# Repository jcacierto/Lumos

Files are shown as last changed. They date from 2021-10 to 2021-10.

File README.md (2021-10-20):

# Lumos
Low-cost, modular luminometer 

**How it works** \
Lumos is a low cost, modular luminometer which can measure the light intensity of luminescent enzymes. The device works by 
measuring the light intensity of the analyte through a TSL237 Light-to-Frequency photodiode. The sensor then converts the
incident light into a 50% duty cycle square wave voltage, which is then picked up by the ESP32 microcontroller's interrupt pins. 
At every rising edge of the square wave input, the microcontroller will call the interrupt service routine (ISR), which increments
the counter variable by 1. The value held by the counter variable is then measured after one second in order to determine the 
frequency in Hz. The frequency detected is directly proportional to the light intensity received from the light source. The output
is then displayed through either the LCD screen built in with the sensor, or on a mobile phone application (currently only available
on Android). The mobile application was made on Thunkable to facilitate BLE connection between the client (phone) and the server (ESP32).

**Materials** 
* ESP32 microcontroller
* TSL237 light-to-frequency photodiode
* LCD1602 screen (with I2C module built-in)
* 0.1uF capacitor
* PLA (for 3D printing)
* Wires

**How to Build**
1. Follow the schematic diagram for the correct wiring on the ESP32 microcontroller. 
2. Upload the .ino sketch to the microcontroller. 
3. On the Thunkable app, search up 'Lumos' by *johncedricaciertot*.
4. Print the CAD models.

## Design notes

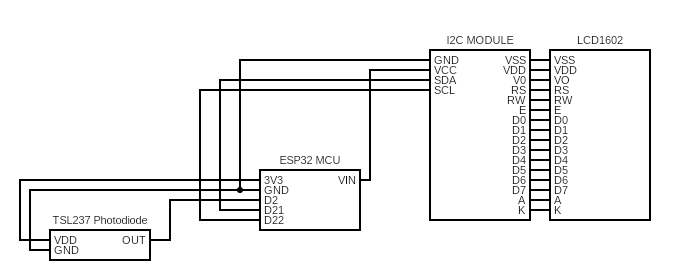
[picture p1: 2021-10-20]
Lumos-Schematic.png

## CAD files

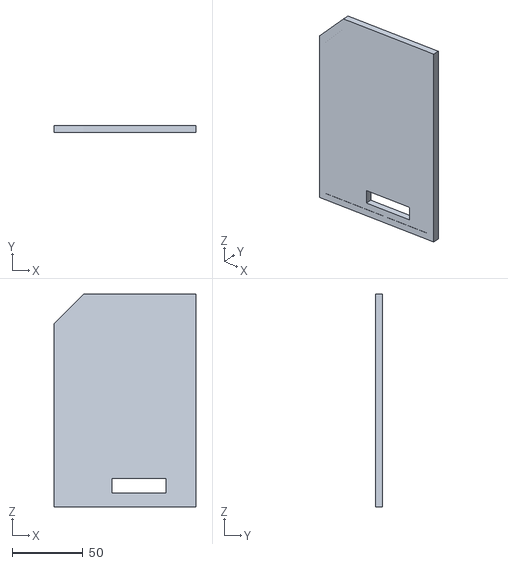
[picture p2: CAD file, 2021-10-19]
stl_files/Main Chassis /MainChassis_Left.stl
100.0 x 5.18 x 150.0

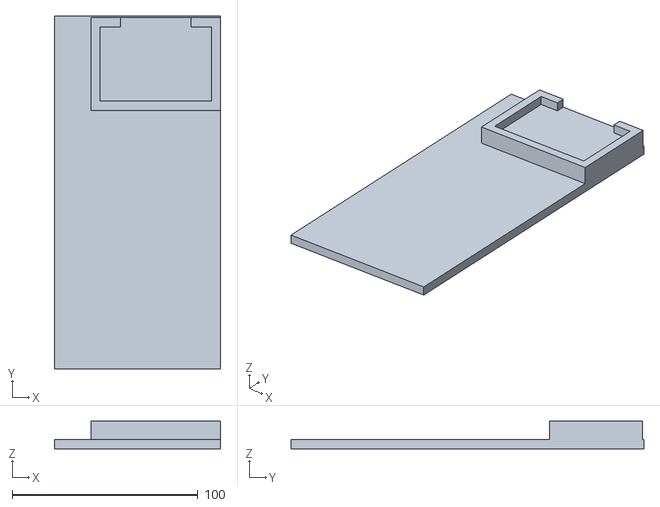
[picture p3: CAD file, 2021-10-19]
stl_files/Main Chassis /MainChassis_Bottom.stl
89.4 x 189.9 x 14.9

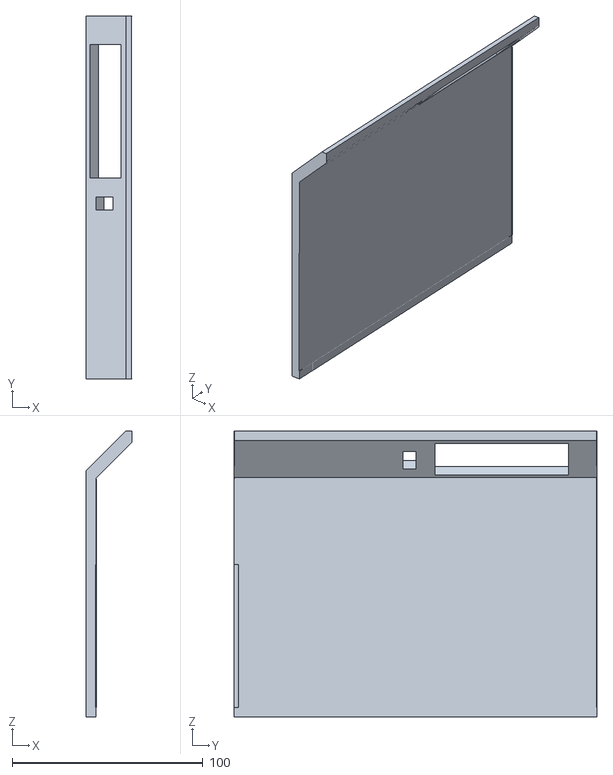
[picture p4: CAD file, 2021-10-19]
stl_files/Main Chassis /MainChassis_Front.stl
23.9 x 190.2 x 150.0

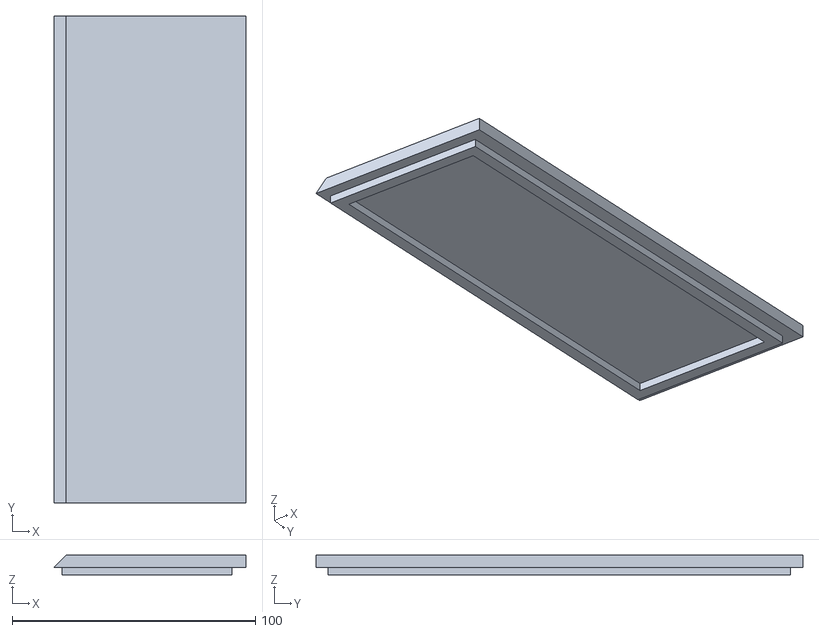
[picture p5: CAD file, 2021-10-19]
stl_files/Main Chassis /MainChassis_Cover.stl
78.9 x 200.1 x 8.10

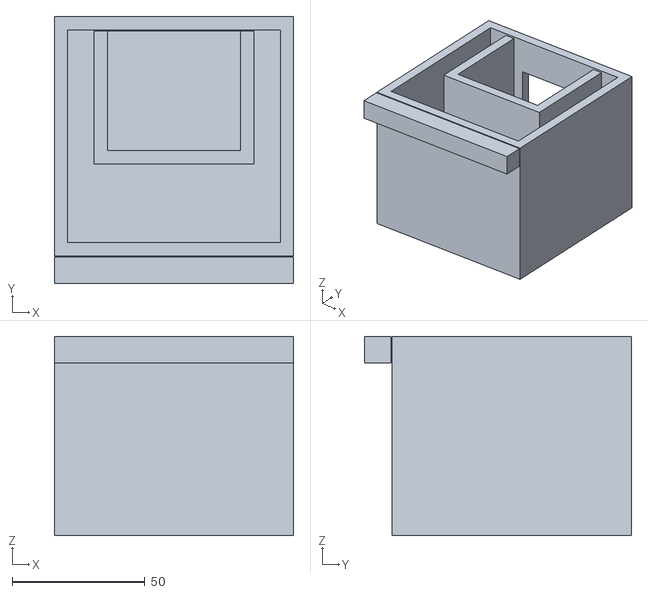
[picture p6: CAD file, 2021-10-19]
stl_files/Sample Chamber/SampleChamber_Main.stl
90.0 x 100.4 x 75.0

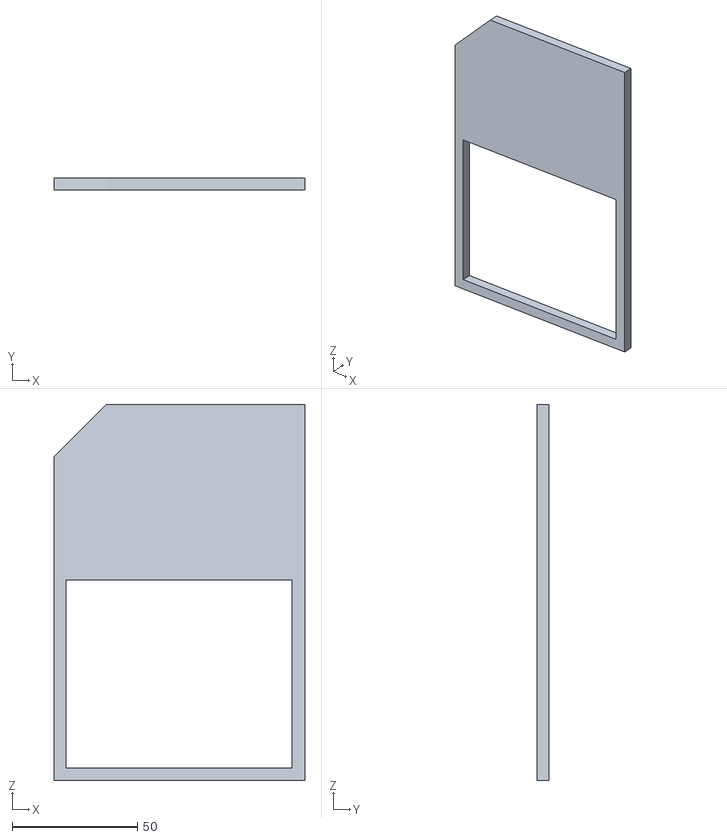
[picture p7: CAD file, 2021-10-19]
stl_files/Main Chassis /MainChassis_Right.stl
100.0 x 4.80 x 150.0

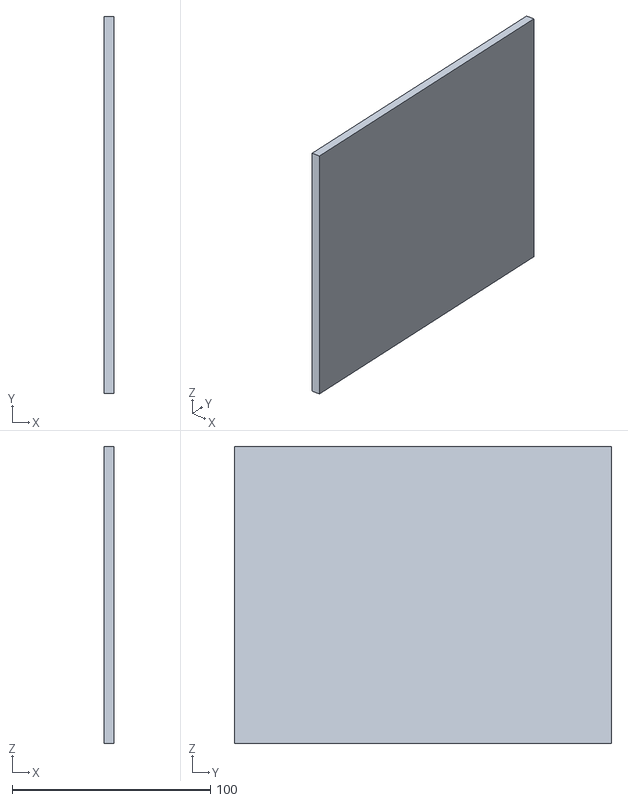
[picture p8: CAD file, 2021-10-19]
stl_files/Main Chassis /MainChassis_Back.stl
4.99 x 190.1 x 150.0

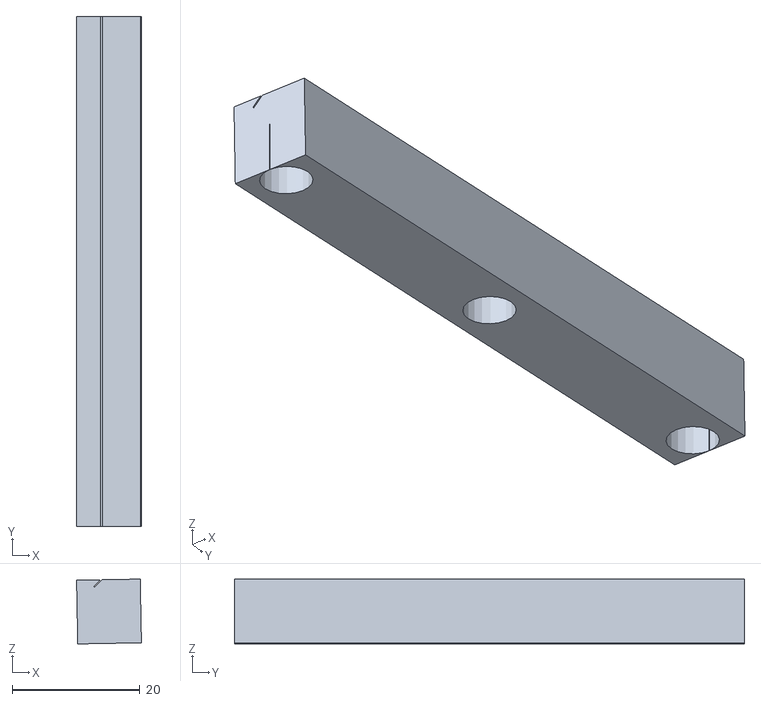
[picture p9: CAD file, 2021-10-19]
stl_files/LCD Holder/LCDHolder_Detachable.stl
10.2 x 80.0 x 10.2

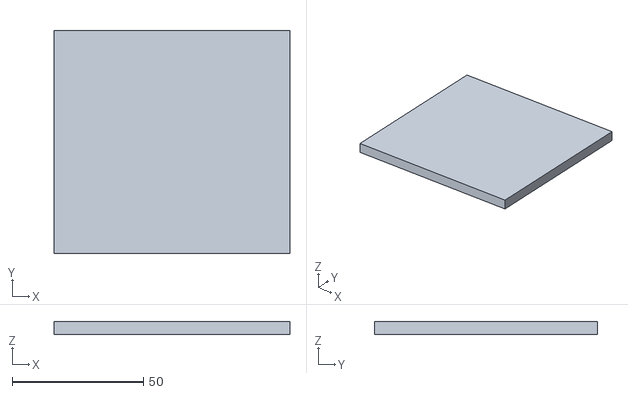
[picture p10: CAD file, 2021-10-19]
stl_files/Sample Chamber/SampleChamber_Top.stl
90.0 x 85.0 x 5.00

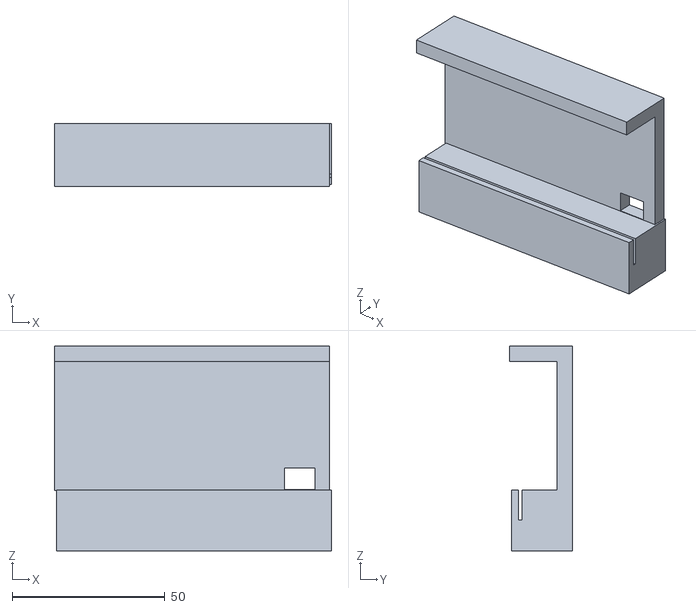
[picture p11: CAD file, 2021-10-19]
stl_files/Sensor Holder/SensorHolder.stl
90.6 x 20.6 x 67.0

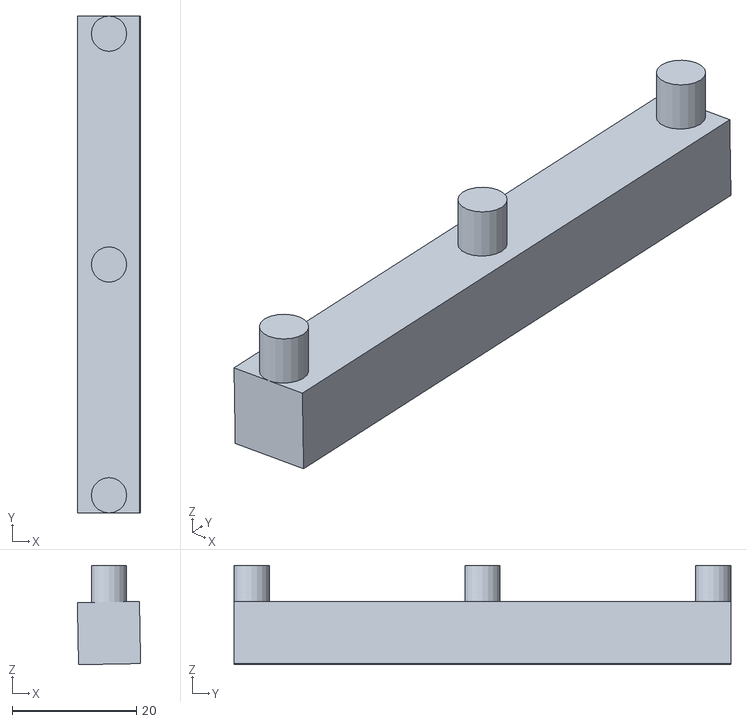
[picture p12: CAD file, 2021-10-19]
stl_files/LCD Holder/LCDHolder_Immobilized.stl
10.2 x 80.0 x 16.0

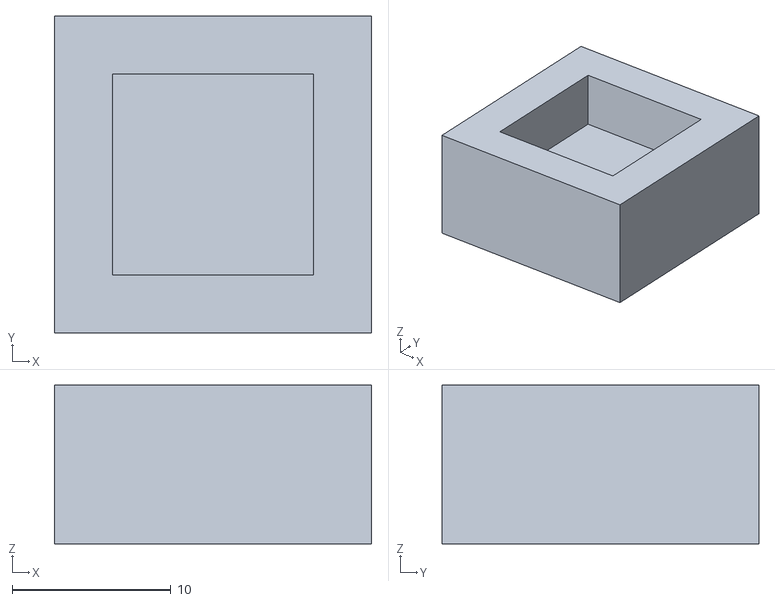
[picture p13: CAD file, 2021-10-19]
stl_files/Sample Chamber/SampleChamber_CuvetteHolder.stl
20.0 x 20.0 x 10.0

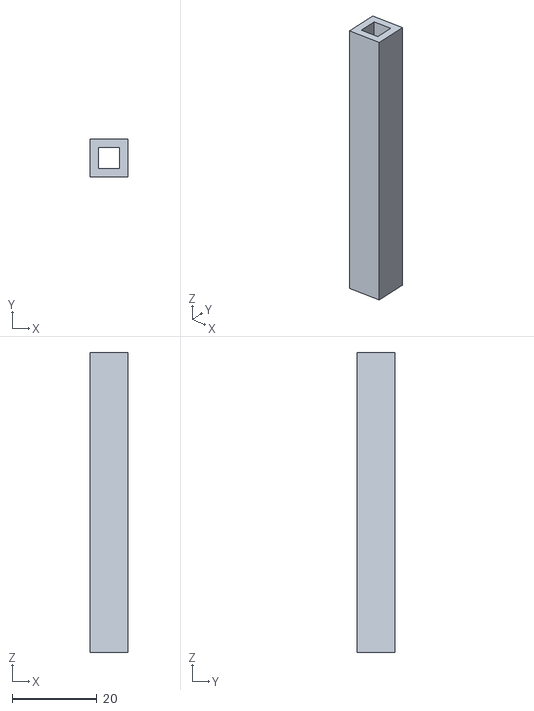
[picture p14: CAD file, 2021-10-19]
stl_files/Sample Chamber/SampleChamber_LDRHolder.stl
9.00 x 9.00 x 71.0

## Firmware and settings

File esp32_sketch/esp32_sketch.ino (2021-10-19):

/**
   Main code for frequency detection of TSL237 sensor
   was heavily based on a pre-written code made by Rob Tillaart
   Made: 2011 - 05 - 16
   Source: https://playground.arduino.cc/Main/TSL235R/

   BLE functionalities were based on code written by Neil Kolban
   https://github.com/nkolban/ESP32_BLE_Arduino

*/

//Libraries needed to run the program:
#include <stdio.h>
#include <stdlib.h>
#include <string>
#include <Wire.h>
#include <LiquidCrystal_I2C.h>

#include <BLEDevice.h>
#include <BLEServer.h>
#include <BLEUtils.h>
#include <BLE2902.h>

LiquidCrystal_I2C lcd(0x27, 16, 2);

//values for setup, frequency measurement, and ambient light detection:
volatile unsigned long cnt = 0;
unsigned long oldcnt = 0;
unsigned long t = 0;
unsigned long last;
int ambient;
boolean hasChosen = false;  //hasChosen is set to true when user chooses a mode. 

BLEServer* pServer = NULL;
BLECharacteristic* pCharacteristic = NULL;
bool deviceConnected = false;
bool oldDeviceConnected = false;
uint32_t value = 0;

//Operation mode: 0 for LCD display, 1 for BLE
int operateMode = 0;

//MACROS SECTION:
#define SERVICE_UUID        "4fafc201-1fb5-459e-8fcc-c5c9c331914b"
#define CHARACTERISTIC_UUID "beb5483e-36e1-4688-b7f5-ea07361b26a8"       



//##-----------------------------------------------------------------
//values for calibration curve:
/**
   Notes:
   M = slope of calibration curve
   B = y-intercept, i.e. x = 0.
*/
float sensorM;
float sensorB;

float expM;
float expB;
//------------------------------------------------------------------


//START OF CODE:

class MyServerCallbacks: public BLEServerCallbacks {
    void onConnect(BLEServer* pServer) {
      deviceConnected = true;
    };

    void onDisconnect(BLEServer* pServer) {
      deviceConnected = false;
    }
};

void irq1() {
  cnt++;
}

void setup() {
  // put your setup code here, to run once:
  Serial.begin(115200);

  pinMode(2, INPUT);  //Pin connected to TSL237 output.
  pinMode(15, INPUT);
  pinMode(5, INPUT_PULLUP);
  digitalWrite(2, HIGH);
  attachInterrupt(digitalPinToInterrupt(2), irq1, RISING); //set interrupt pin to pin 2. 

  
  
  // Create the BLE Device
  BLEDevice::init("ESP32");

  // Create the BLE Server
  pServer = BLEDevice::createServer();
  pServer->setCallbacks(new MyServerCallbacks());

  // Create the BLE Service
  BLEService *pService = pServer->createService(SERVICE_UUID);

  // Create a BLE Characteristic
  pCharacteristic = pService->createCharacteristic(
                      CHARACTERISTIC_UUID,
                      BLECharacteristic::PROPERTY_READ   |
                      BLECharacteristic::PROPERTY_WRITE  |
                      BLECharacteristic::PROPERTY_NOTIFY |
                      BLECharacteristic::PROPERTY_INDICATE
                    );

  // Create a BLE Descriptor
  pCharacteristic->addDescriptor(new BLE2902());

  // Start the service
  pService->start();

  // Start advertising
  BLEAdvertising *pAdvertising = BLEDevice::getAdvertising();
  pAdvertising->addServiceUUID(SERVICE_UUID);
  pAdvertising->setScanResponse(false);
  pAdvertising->setMinPreferred(0x0);  // set value to 0x00 to not advertise this parameter
  BLEDevice::startAdvertising();

}//end of setup().

/*
   this function will print every 1000 milliseconds (cnt will increment during this time),
   current millis() value will be assigned to unsigned long last,
   t will get the current value of cnt (which is updated by irq1),
   hz will be the difference between current cnt and old cnt.
   value for hz will be printed after every 1000 milliseconds (1 second)
   NOTE: Hertz is number of cycles PER SECOND, hence the measurement every 1000 ms.
*/
void loop() {
  
  if(digitalRead(5) == HIGH){
    operateMode = 1;
  }
  else{
    operateMode = 0;
  }
  Serial.println(digitalRead(5));
  
  if (operateMode == 0) {
    if (millis() - last >= 1000) {
      if (ambient > 0) {
        lcd.setCursor(0, 1);
        lcd.print("Close lid.");
      }
      last = millis();
      t = cnt;
      unsigned long hz = t - oldcnt;
      lcd.init();
      lcd.backlight();
      lcd.setCursor(0, 0);
      lcd.print("Reading...");
      lcd.setCursor(0, 1);
      lcd.print("FRQ:");
      lcd.print(hz);

      oldcnt = t;
    }
  }

  else if (operateMode == 1) {
    
    unsigned long hz;

    if (deviceConnected) {
      if (millis() - last >= 1000) {
        last = millis();
        t = cnt;
        hz = t - oldcnt;
        oldcnt = t;
        lcd.setCursor(0,1);
        lcd.print(hz);
        char hzStr[10];
        char* inStr = itoa(hz, hzStr, 10);
  
        pCharacteristic->setValue(inStr);
        pCharacteristic->notify();

        delay(3);
      }
       
    }

    // disconnecting
    if (!deviceConnected && oldDeviceConnected) {
      delay(500); // give the bluetooth stack the chance to get things ready
      pServer->startAdvertising(); // restart advertising
      Serial.println("start advertising");
      oldDeviceConnected = deviceConnected;
    }

    // connecting
    if (deviceConnected && !oldDeviceConnected) {
      // do stuff here on connecting
      oldDeviceConnected = deviceConnected;
    }
  }

}//end of loop().

//END OF FILE

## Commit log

2021-10-19 added STL files for chassis
    [LCDHolder_Detachable.stl, LCDHolder_Immobilized.stl, MainChassis_Back.stl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]
2021-10-20 added Lumos schematic diagram
